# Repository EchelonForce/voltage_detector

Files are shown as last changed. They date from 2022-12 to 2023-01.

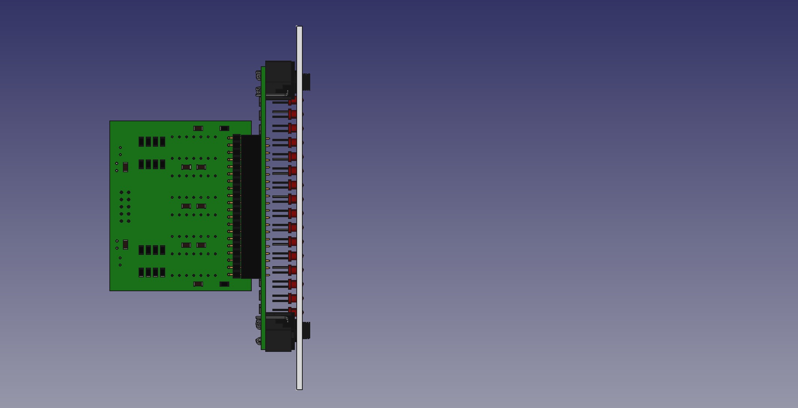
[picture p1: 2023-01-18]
front_panel_v1/render3.png

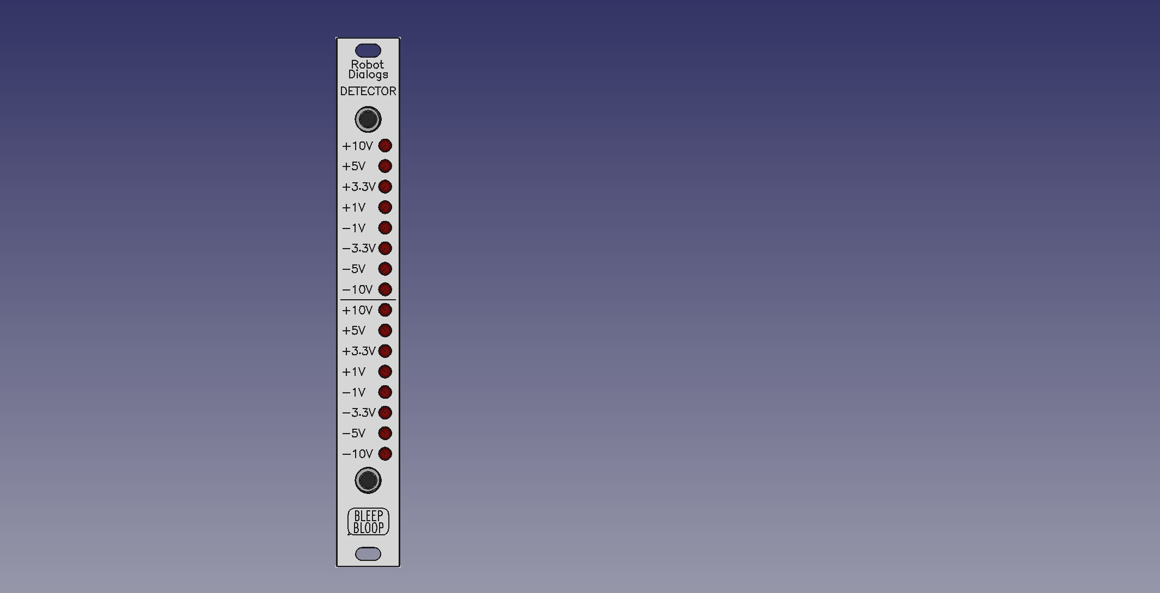
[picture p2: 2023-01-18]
front_panel_v1/render1.png

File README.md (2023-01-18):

# Eurorack Voltage Detector 

This is a design for a eurorack voltage detector.

Full writeup: https://www.robotdialogs.com/2023/01/eurorack-voltage-detector.html

This work is licensed under a Creative Commons Attribution-NonCommercial-ShareAlike 4.0 International License. https://creativecommons.org/licenses/by-nc-sa/4.0/

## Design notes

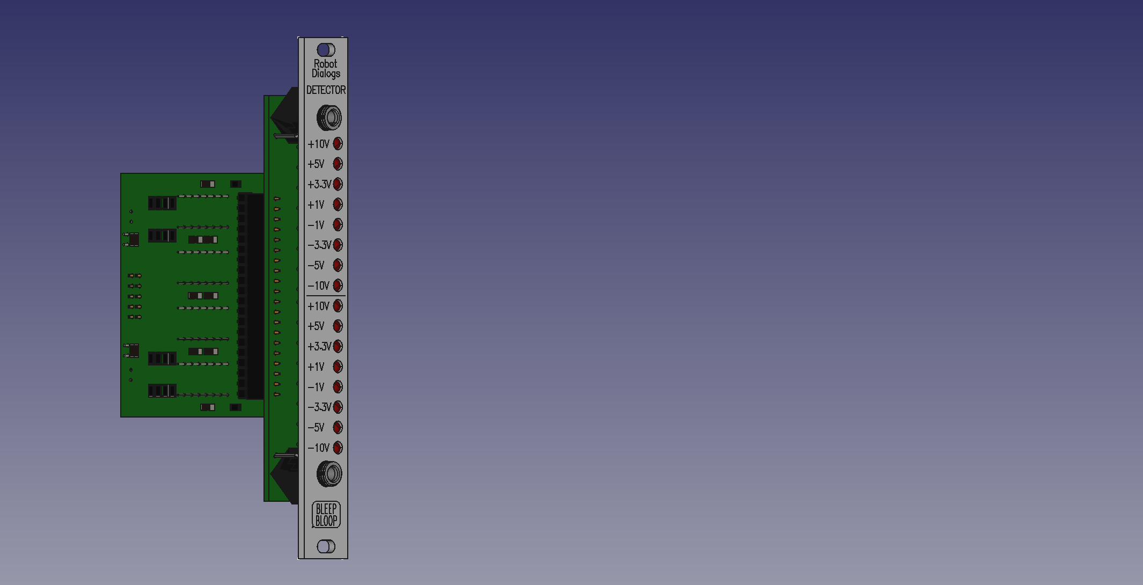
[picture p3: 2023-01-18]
front_panel_v1/render2.png

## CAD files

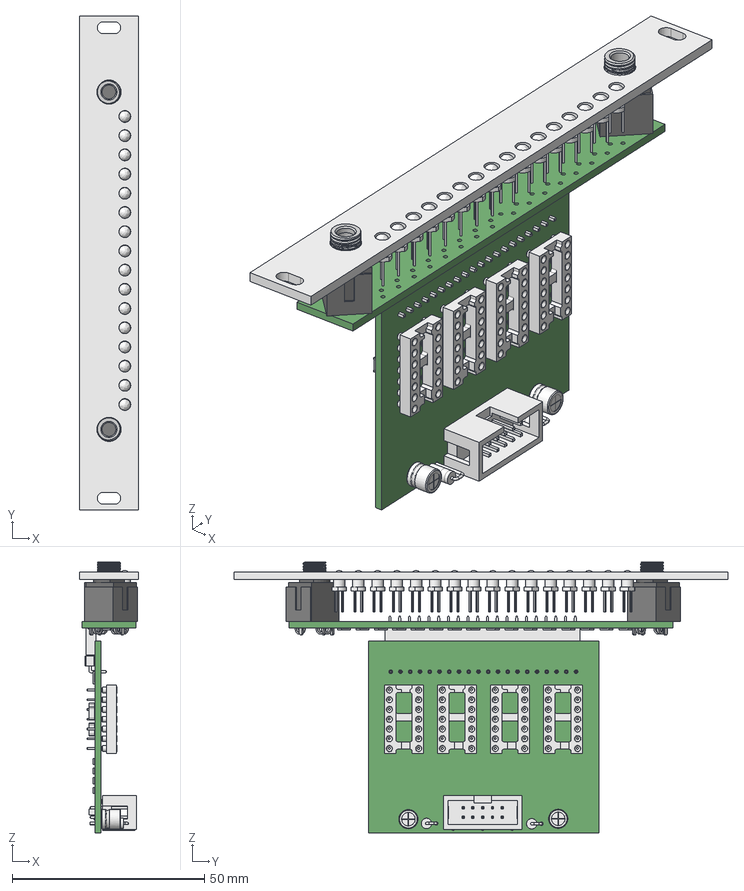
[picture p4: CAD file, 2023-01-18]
front_panel_v1/voltage_detector_v1_front_panel_v1.FCStd
15.2 x 128.5 x 70.5 mm
_autosave-voltage_detector_v1 PCB
_autosave-voltage_detector_v1 PCB001

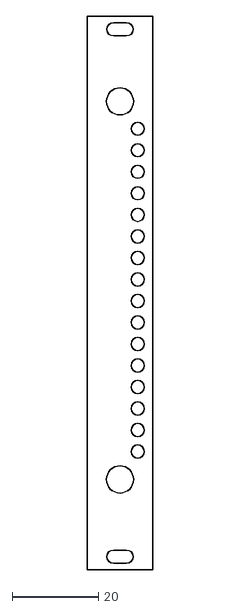
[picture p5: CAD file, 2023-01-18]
front_panel_v1/voltage_detector_v1_front_panel_v1_no_engraving.dxf
15.2 x 128.5

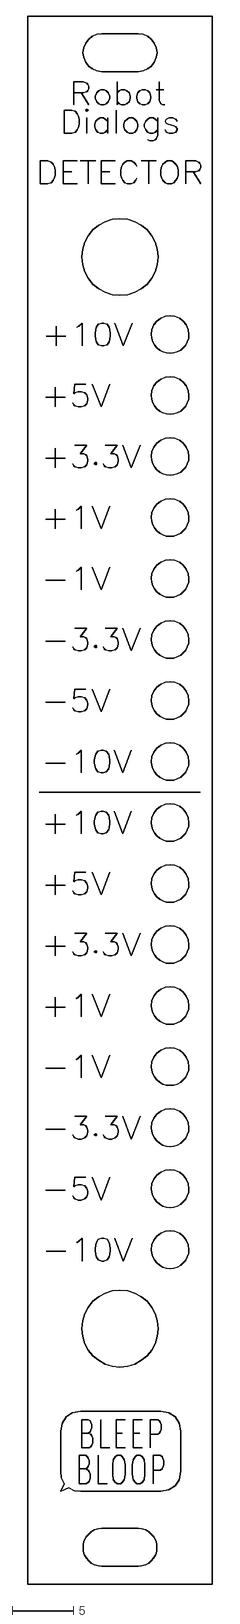
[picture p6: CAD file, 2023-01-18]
front_panel_v1/voltage_detector_v1_front_panel_v1_engraving.dxf
15.1 x 128.4

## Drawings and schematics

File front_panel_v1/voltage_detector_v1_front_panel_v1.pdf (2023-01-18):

1

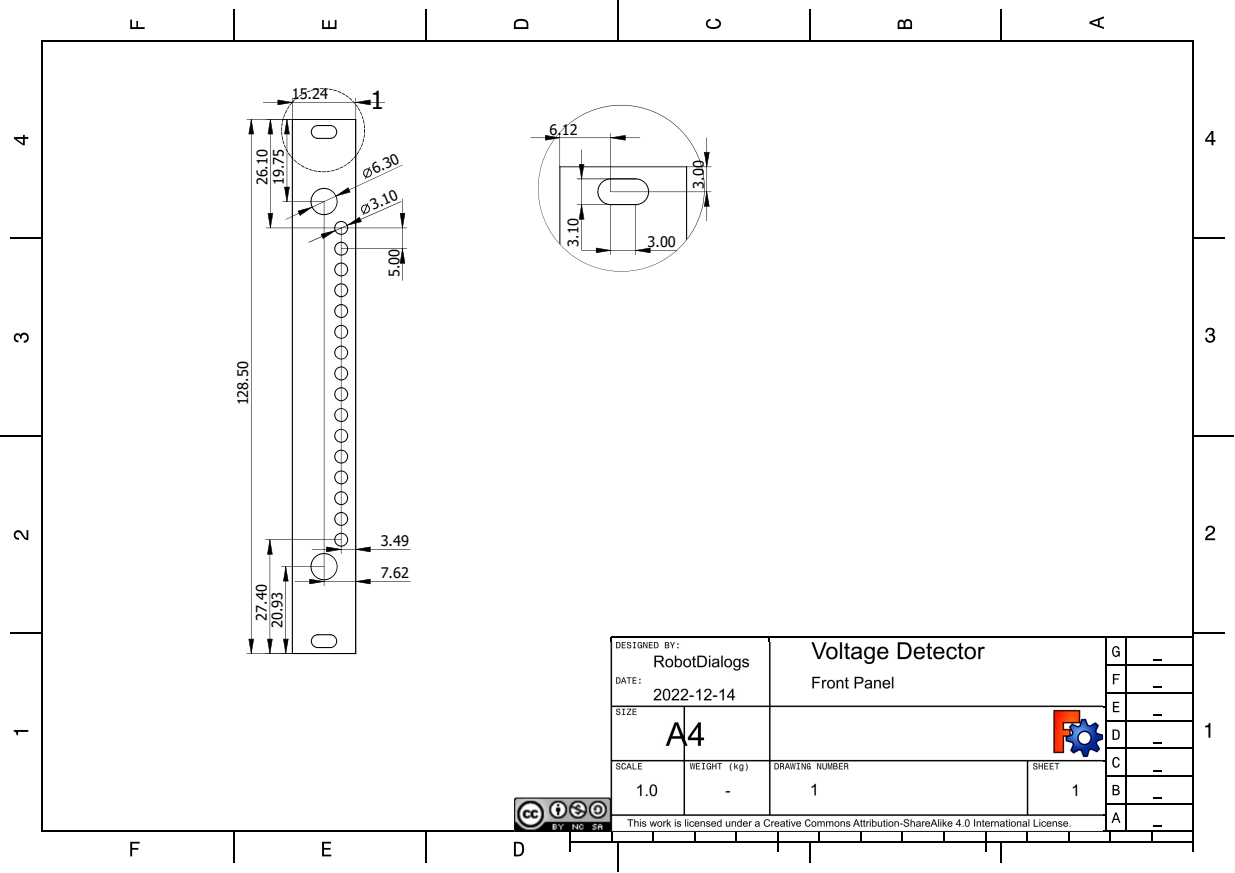
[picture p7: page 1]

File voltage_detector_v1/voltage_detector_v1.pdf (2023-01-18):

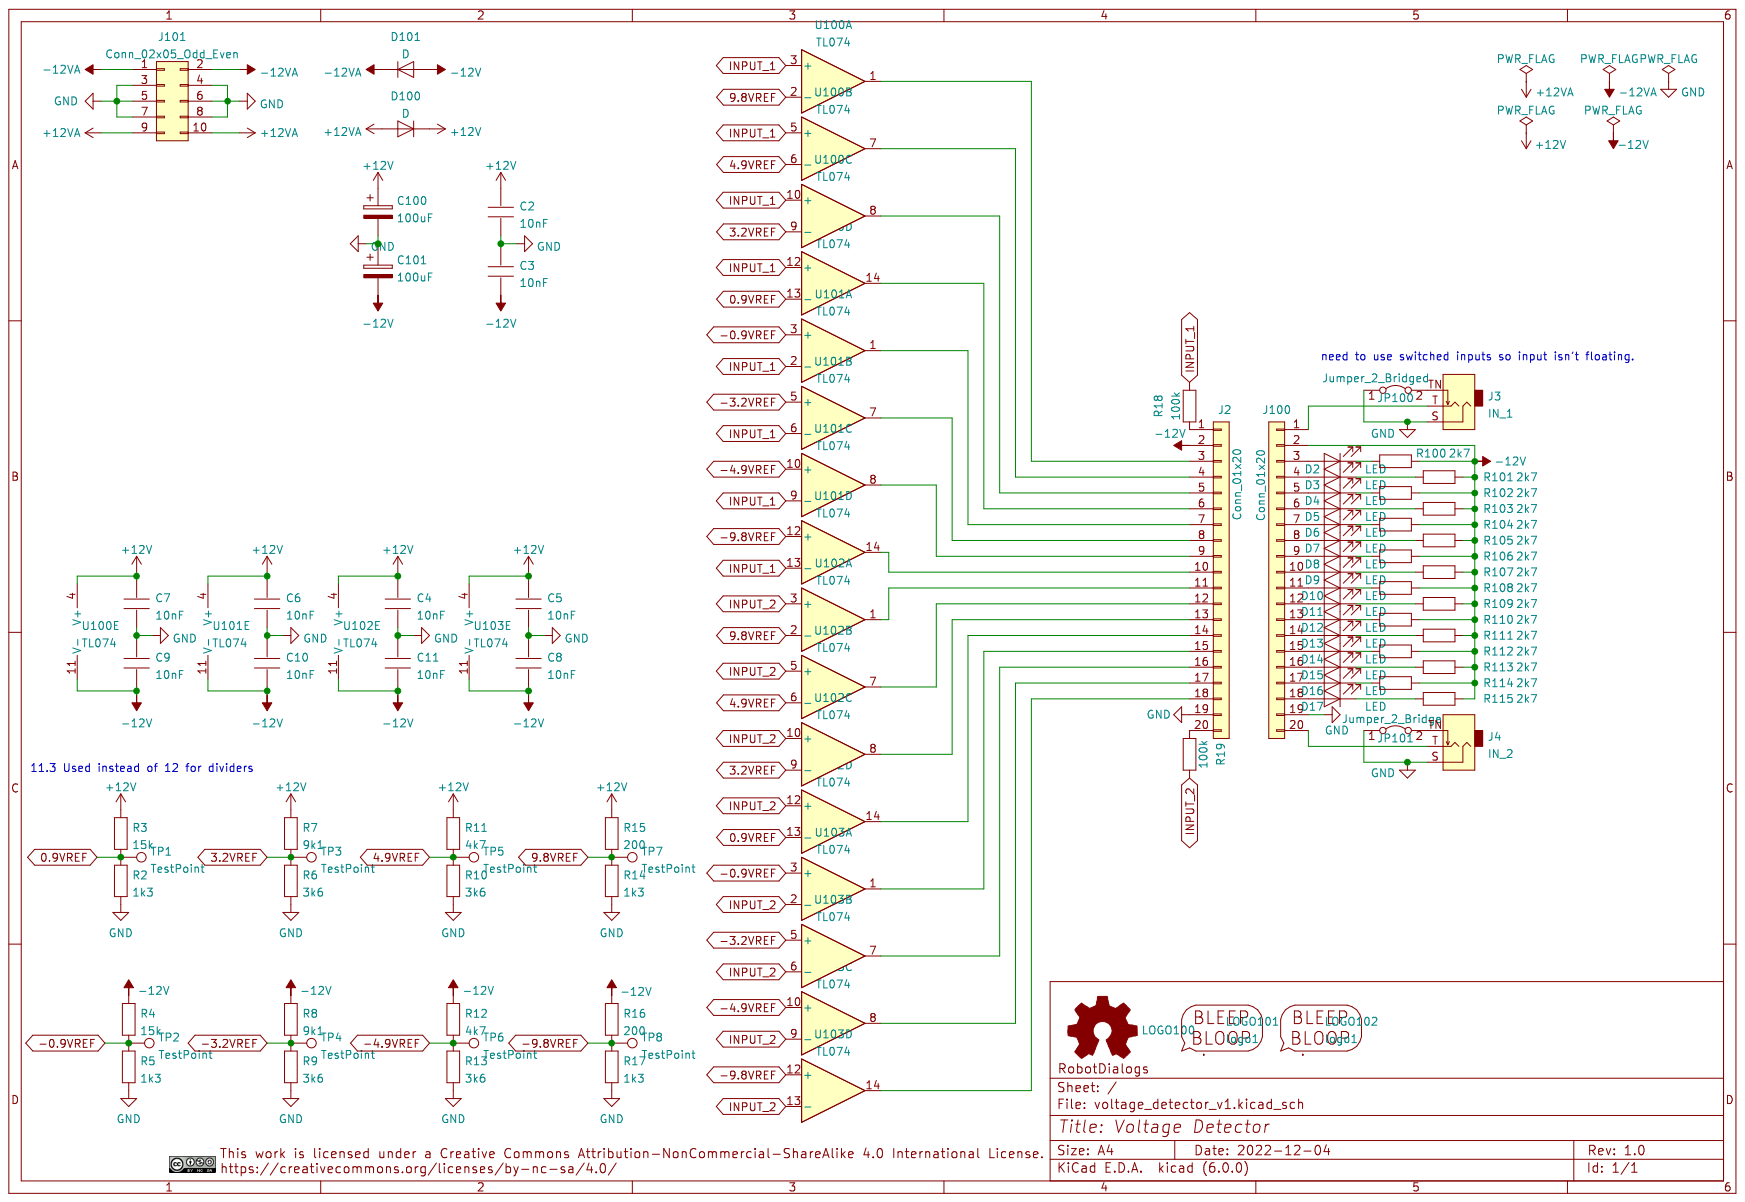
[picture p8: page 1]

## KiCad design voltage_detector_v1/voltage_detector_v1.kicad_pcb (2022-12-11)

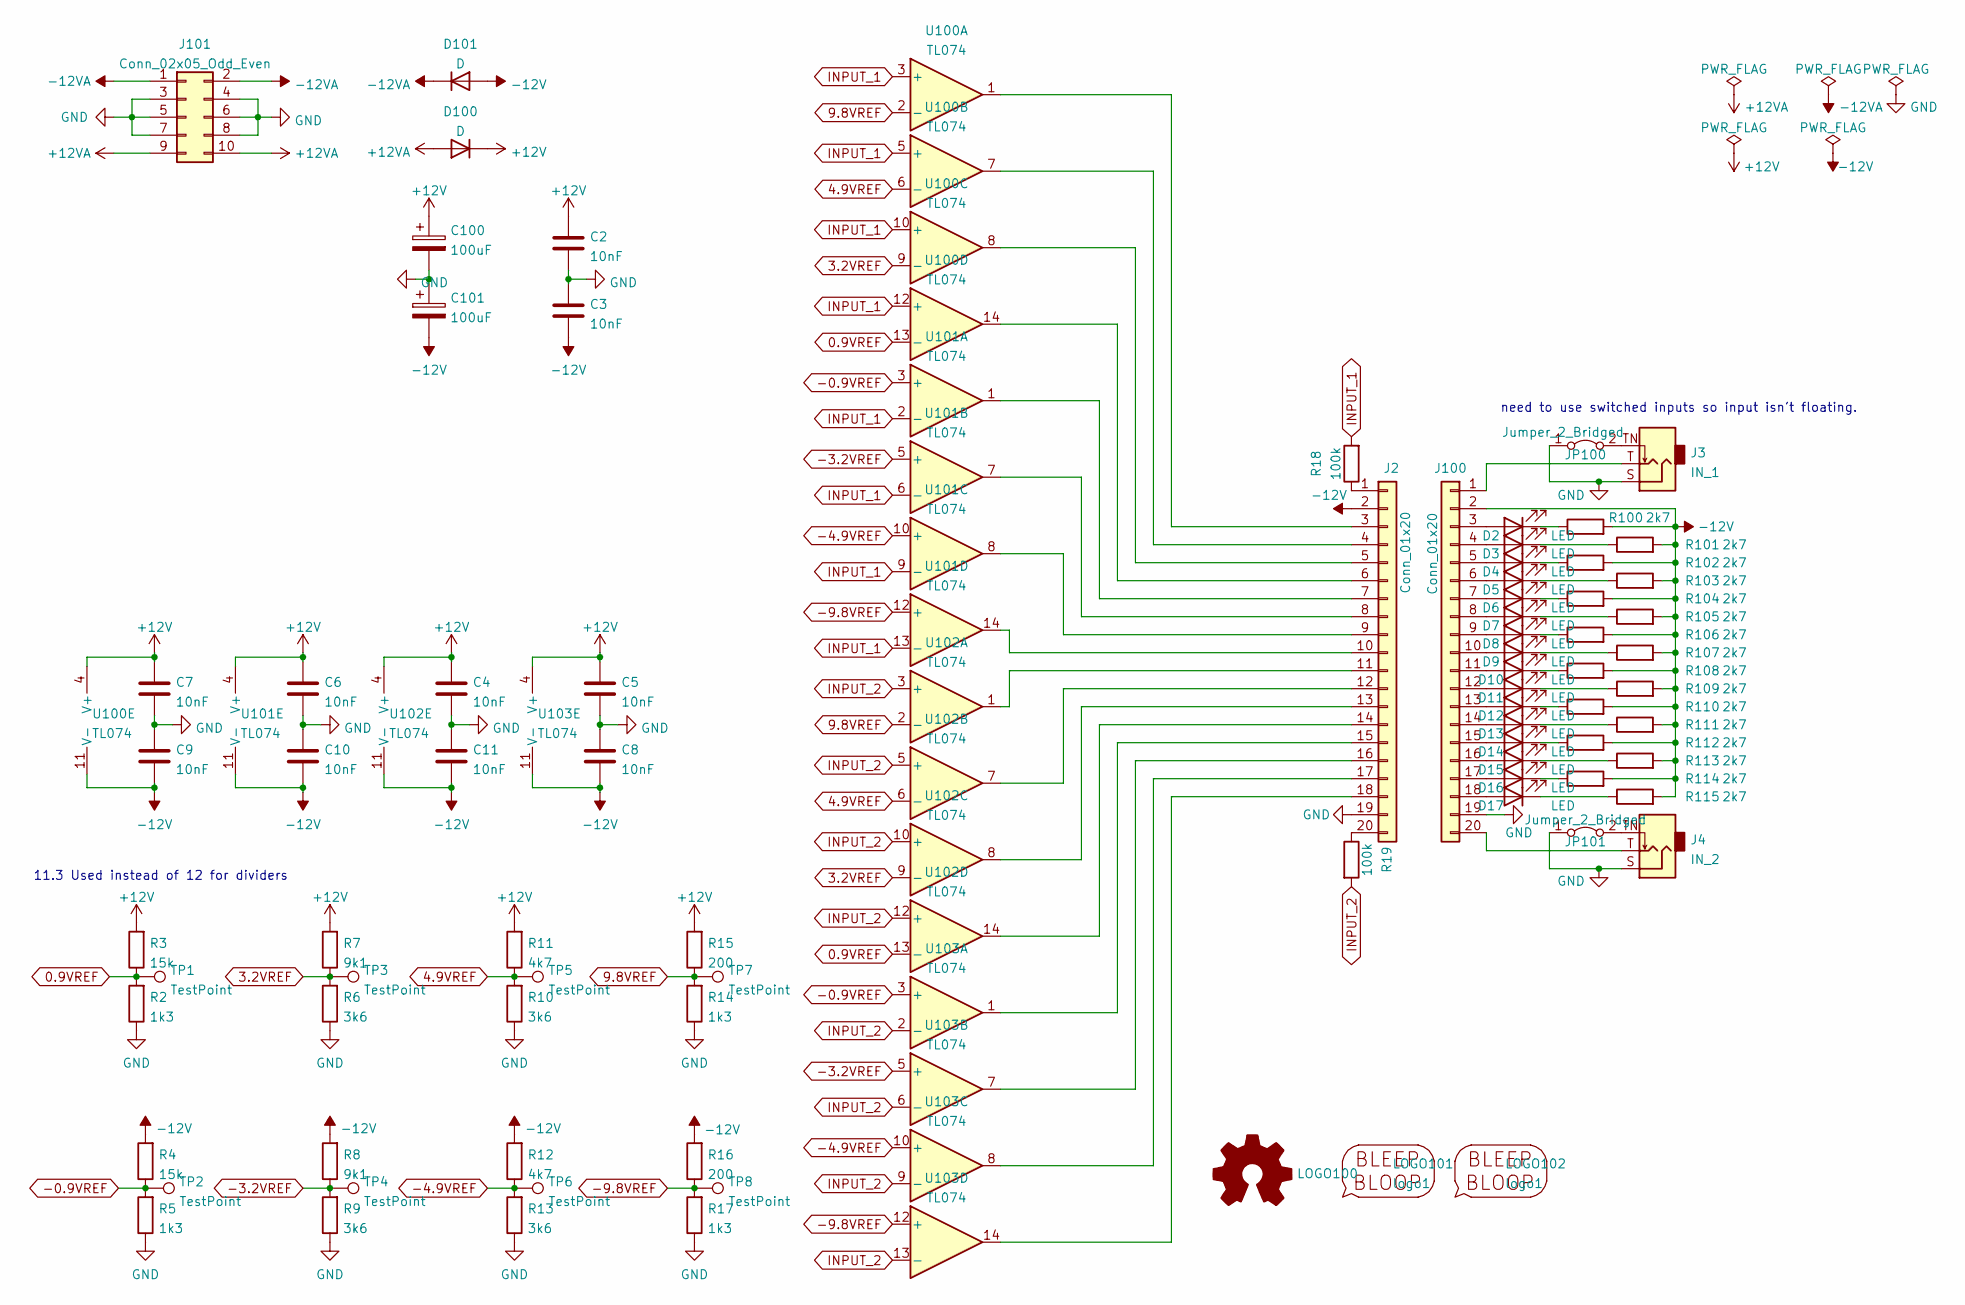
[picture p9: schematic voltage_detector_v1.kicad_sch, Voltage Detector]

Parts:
C2, C3, C4, C5, C6, C7, C8, C9, C10, C11: 10nF; C_1206_3216Metric_Pad1.33x1.80mm_HandSolder
C100, C101: 100uF; CP_Radial_D5.0mm_P2.50mm
D2, D3, D4, D5, D6, D7, D8, D9, D10, D11, D12, D13, D14, D15, D16, D17: LED; LED_D3.0mm
D100, D101: D; D_A-405_P2.54mm_Vertical_KathodeUp
J2: Conn_01x20; PinHeader_1x20_P2.54mm_Horizontal
J3: IN_1; Jack_3.5mm_MJ-355W_and_PJ398SM_Vertical
J4: IN_2; Jack_3.5mm_MJ-355W_and_PJ398SM_Vertical
J100: Conn_01x20; PinSocket_1x20_P2.54mm_Vertical
J101: Conn_02x05_Odd_Even; IDC-Header_2x05_P2.54mm_Vertical
JP100, JP101: Jumper_2_Bridged; SolderJumper-2_P1.3mm_Bridged_Pad1.0x1.5mm
LOGO100: Logo_Open_Hardware_Small; OSHW-Symbol_6.7x6mm_SilkScreen
LOGO101: logo1; Logo1
LOGO102: logo1; Logo2
R2, R5, R14, R17: 1k3; R_1206_3216Metric_Pad1.30x1.75mm_HandSolder
R3, R4: 15k; R_1206_3216Metric_Pad1.30x1.75mm_HandSolder
R6, R9, R10, R13: 3k6; R_1206_3216Metric_Pad1.30x1.75mm_HandSolder
R7, R8: 9k1; R_1206_3216Metric_Pad1.30x1.75mm_HandSolder
R11, R12: 4k7; R_1206_3216Metric_Pad1.30x1.75mm_HandSolder
R15, R16: 200; R_1206_3216Metric_Pad1.30x1.75mm_HandSolder
R18, R19: 100k; R_1206_3216Metric_Pad1.30x1.75mm_HandSolder
R100, R101, R102, R103, R104, R105, R106, R107, R108, R109, R110, R111, R112, R113, R114, R115: 2k7; R_1206_3216Metric_Pad1.30x1.75mm_HandSolder
TP1, TP2, TP3, TP4, TP5, TP6, TP7, TP8: TestPoint; TestPoint_Pad_D1.0mm_minimal
U100, U101, U102, U103: TL074; DIP-14_W7.62mm_Socket_LongPads

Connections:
0.9VREF: R2.2, R3.1, TP1.1, U100.13 (-), U102.13 (-)
3.2VREF: R6.2, R7.1, TP3.1, U100.9 (-), U102.9 (-)
4.9VREF: R10.2, R11.1, TP5.1, U100.6 (-), U102.6 (-)
9.8VREF: R14.2, R15.1, TP7.1, U100.2 (-), U102.2 (-)
+12V: C2.1, C4.1, C5.1, C6.1, C7.1, C100.1, D100.1 (K), R3.2, R7.2, R11.2, R15.2, U100.4 (V+), U101.4 (V+), U102.4 (V+), U103.4 (V+)
+12VA: D100.2 (A), J101.9, J101.10
-0.9VREF: R4.1, R5.2, TP2.1, U101.3 (+), U103.3 (+)
-3.2VREF: R8.1, R9.2, TP4.1, U101.5 (+), U103.5 (+)
-4.9VREF: R12.1, R13.2, TP6.1, U101.10 (+), U103.10 (+)
-9.8VREF: R16.1, R17.2, TP8.1, U101.12 (+), U103.12 (+)
-12V: C3.2, C8.2, C9.2, C10.2, C11.2, C101.2, D101.2 (A), J2.2, J100.2, R4.2, R8.2, R12.2, R16.2, R100.2, R101.2, R102.2, R103.2, R104.2, R105.2, R106.2, R107.2, R108.2, R109.2, R110.2, R111.2, R112.2, R113.2, R114.2, R115.2, U100.11 (V-), U101.11 (V-), U102.11 (V-), U103.11 (V-)
-12VA: D101.1 (K), J101.1, J101.2
GND: C2.2, C3.1, C4.2, C5.2, C6.2, C7.2, C8.1, C9.1, C10.1, C11.1, C100.2, C101.1, J2.19, J3.S, J4.S, J100.19, J101.3, J101.4, J101.5, J101.6, J101.7, J101.8, JP100.1 (A), JP101.1 (A), R2.1, R5.1, R6.1, R9.1, R10.1, R13.1, R14.1, R17.1
INPUT_1: R18.2, U100.3 (+), U100.5 (+), U100.10 (+), U100.12 (+), U101.2 (-), U101.6 (-), U101.9 (-), U101.13 (-)
INPUT_2: R19.2, U102.3 (+), U102.5 (+), U102.10 (+), U102.12 (+), U103.2 (-), U103.6 (-), U103.9 (-), U103.13 (-)
unnamed: D2.1 (K), R100.1
unnamed: D2.2 (A), J100.3
unnamed: D3.1 (K), R101.1
unnamed: D3.2 (A), J100.4
unnamed: D4.1 (K), R102.1
unnamed: D4.2 (A), J100.5
unnamed: D5.1 (K), R103.1
unnamed: D5.2 (A), J100.6
unnamed: D6.1 (K), R104.1
unnamed: D6.2 (A), J100.7
unnamed: D7.1 (K), R105.1
unnamed: D7.2 (A), J100.8
unnamed: D8.1 (K), R106.1
unnamed: D8.2 (A), J100.9
unnamed: D9.1 (K), R107.1
unnamed: D9.2 (A), J100.10
unnamed: D10.1 (K), R108.1
unnamed: D10.2 (A), J100.11
unnamed: D11.1 (K), R109.1
unnamed: D11.2 (A), J100.12
unnamed: D12.1 (K), R110.1
unnamed: D12.2 (A), J100.13
unnamed: D13.1 (K), R111.1
unnamed: D13.2 (A), J100.14
unnamed: D14.1 (K), R112.1
unnamed: D14.2 (A), J100.15
unnamed: D15.1 (K), R113.1
unnamed: D15.2 (A), J100.16
unnamed: D16.1 (K), R114.1
unnamed: D16.2 (A), J100.17
unnamed: D17.1 (K), R115.1
unnamed: D17.2 (A), J100.18
unnamed: J2.1, R18.1
unnamed: J2.3, U100.1
unnamed: J2.4, U100.7
unnamed: J2.5, U100.8
unnamed: J2.6, U100.14
unnamed: J2.7, U101.1
unnamed: J2.8, U101.7
unnamed: J2.9, U101.8
unnamed: J2.10, U101.14
unnamed: J2.11, U102.1
unnamed: J2.12, U102.7
unnamed: J2.13, U102.8
unnamed: J2.14, U102.14
unnamed: J2.15, U103.1
unnamed: J2.16, U103.7
unnamed: J2.17, U103.8
unnamed: J2.18, U103.14
unnamed: J2.20, R19.1
unnamed: J3.T, J100.1
unnamed: J3.TN, JP100.2 (B)
unnamed: J4.TN, JP101.2 (B)
unnamed: J4.T, J100.20

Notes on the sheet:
11.3 Used instead of 12 for dividers
need to use switched inputs so input isn't floating.

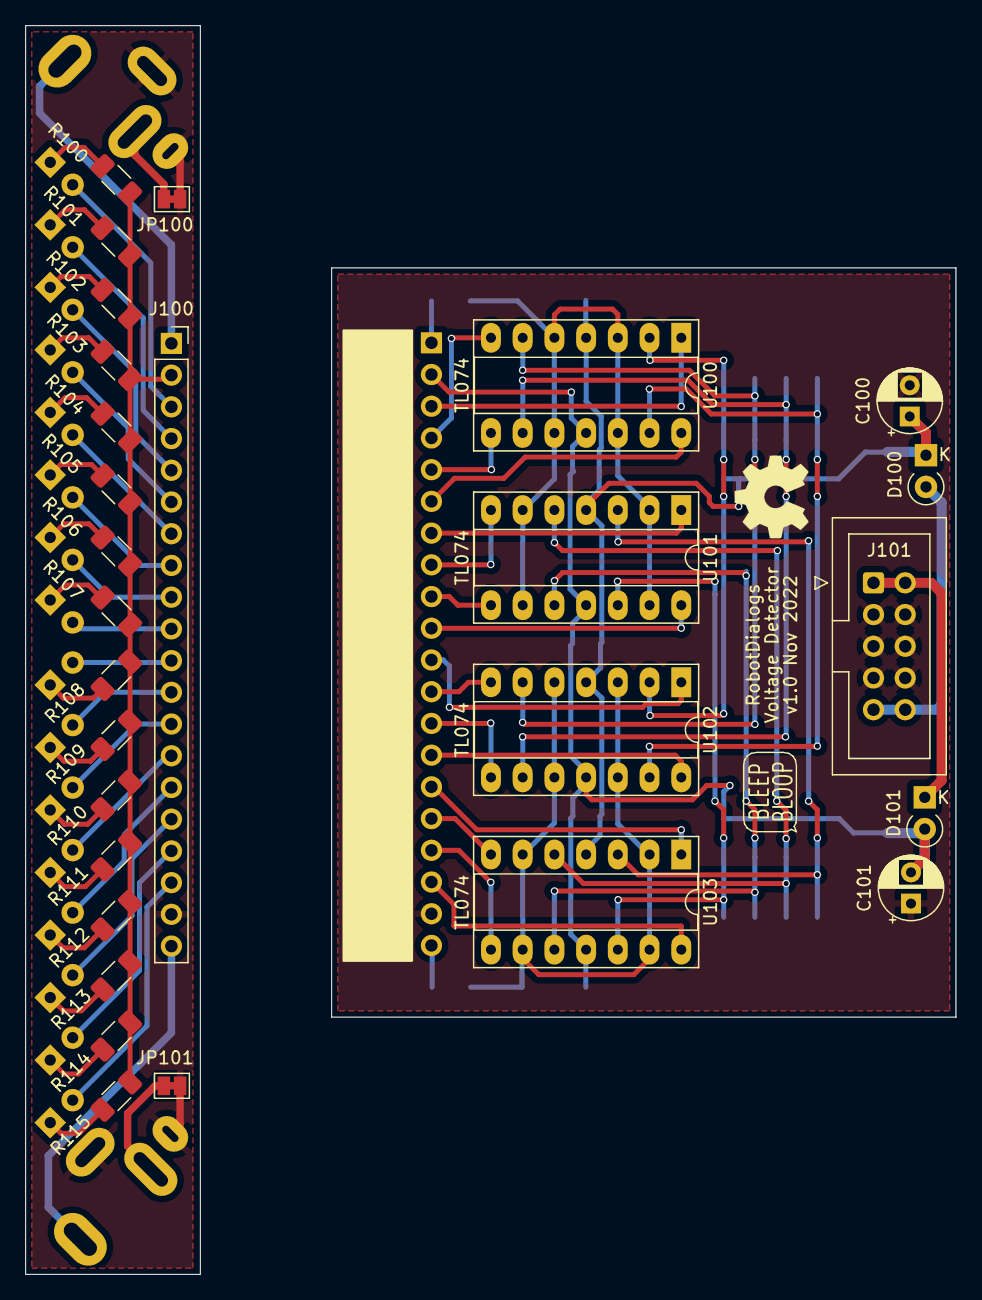
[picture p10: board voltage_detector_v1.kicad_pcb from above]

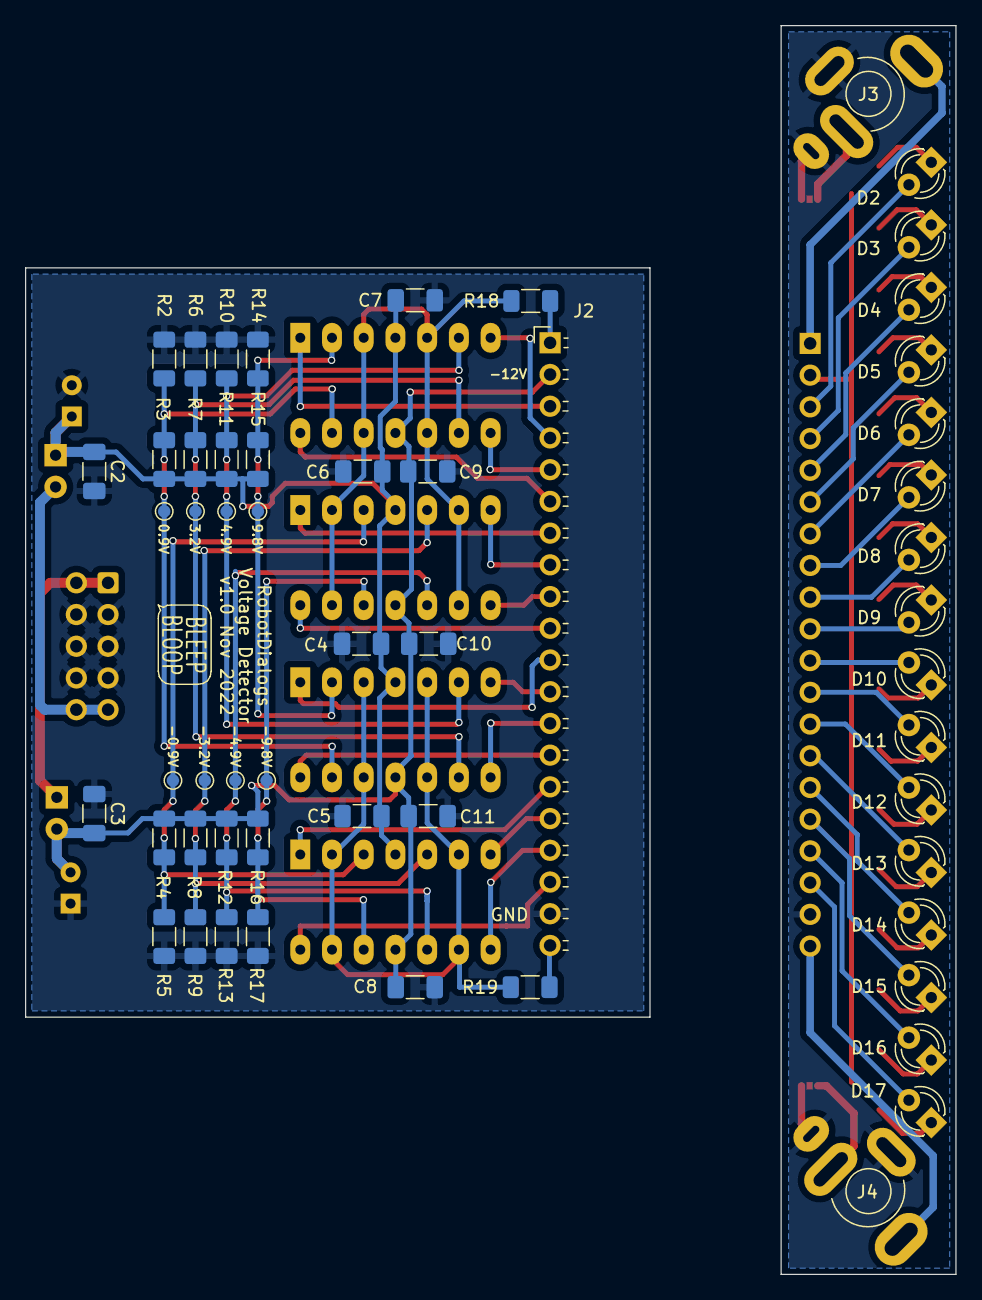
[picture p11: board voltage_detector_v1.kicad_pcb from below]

Board: 2 copper layers, 74.5 x 100.0 mm, 86 parts (55 on the bottom side), 69 nets.

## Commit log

2022-12-11 Schematic and PCB routing
    [voltage_detector_v1.kicad_pcb, voltage_detector_v1.kicad_sch]
2022-12-11 Panelized v1
    [voltage_detector_v1_back_panelized.kicad_pcb, voltage_detector_v1_front_panelized.kicad_pcb]
2023-01-18 Schematic v1 pdf
2023-01-18 Front Panel v1
    [voltage_detector_v1_front_panel_v1.FCStd, voltage_detector_v1_front_panel_v1_engraving.dxf, voltage_detector_v1_front_panel_v1_no_engraving.dxf]
